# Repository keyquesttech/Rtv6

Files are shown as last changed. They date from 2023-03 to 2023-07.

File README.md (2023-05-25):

<p align="center" style="margin-bottom: 0px !important;">
 <a href="https://github.com/keyquesttech">
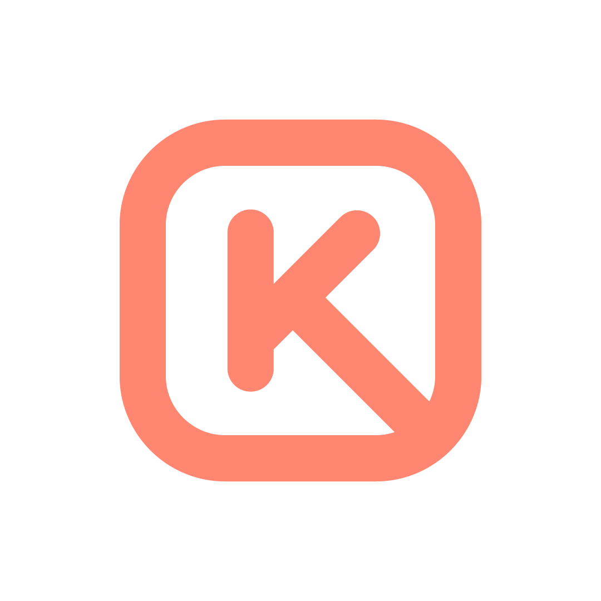
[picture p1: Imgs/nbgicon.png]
Keyquest logo
  
   <a href="https://www.behance.net/matiasms">
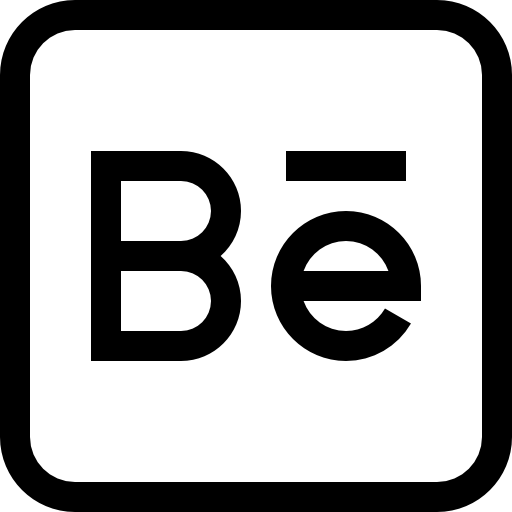
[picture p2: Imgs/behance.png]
    
</p>

<p align="center" style="margin-bottom: 0px !important;">
  <a href="https://igg.me/at/rtv6/x/33605500#/">
    
</p>
 
 <p align="center" style="margin-top: 200px !important;">
  <h2 align="center" style="margin-bottom: 100px;">For info and sales PM via discord at: TC#4730 or click the indiegogo image above</h2>
</p>
 
</div>
<p align="center" >RtV6</p>
<p align="center" >A rvo nozzle adapter to make any V6 nozzle a quick change nozzle</p>
<p align="center" >Rvo CHT? Rvo Diamond? Rvo Emerald?</p>
<p align="center" >All possible now.</p>
</div>

<div align="center" >
  
  
  


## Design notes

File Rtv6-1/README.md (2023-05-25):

<p align="center" style="margin-top: 100px !important;">
  <h2 align="center" style="margin-bottom: 0px;">RtV6 V1:</h2>
</p>

</div>

 - Brass Body.
 - Titanium alloy inner tube.
 - Adds 6mm from heater base to tip of nozzle.

<p align="center" style="margin-bottom: 0px !important;">
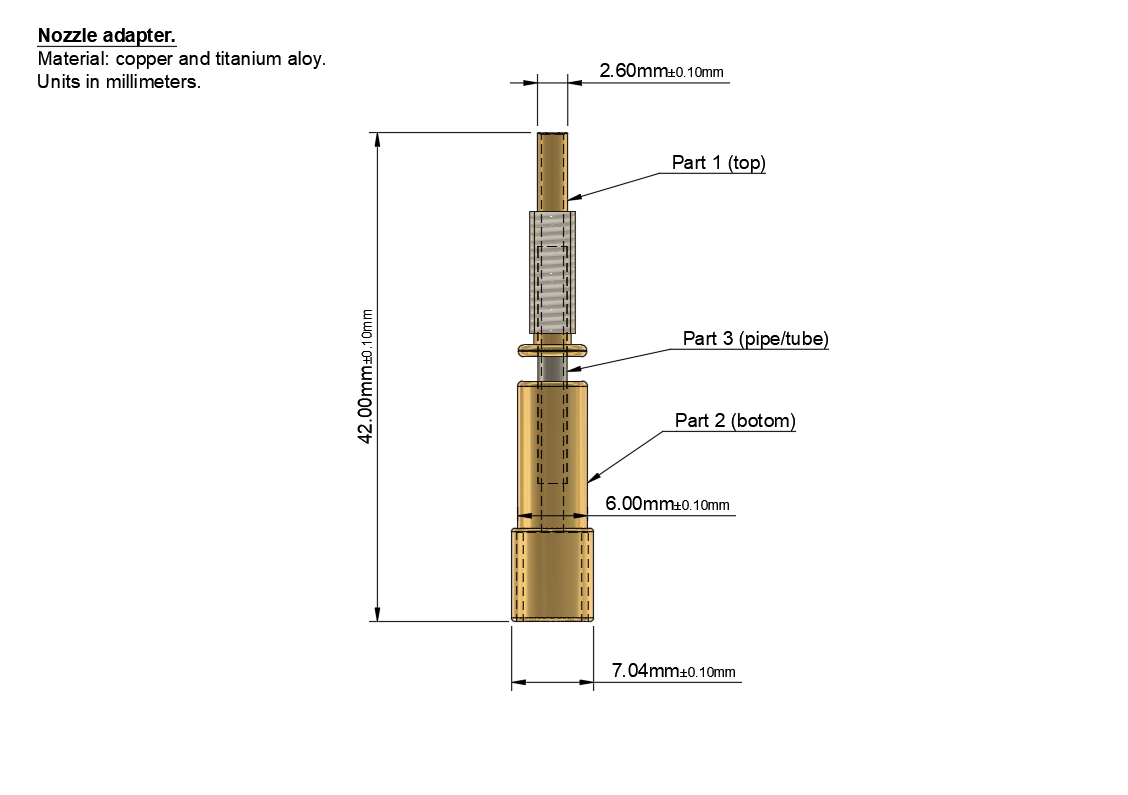
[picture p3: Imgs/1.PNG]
Keyquest logo
  
</p>

<p align="center" style="margin-top: 100px !important;">
  <h2 align="center" style="margin-bottom: 0px;">Tips and tricks:</h2>
</p>

**Nozzle soak:**
In general it's always a good idea to wait a bit to start printing to let the nozzle zoak and stabilize at the desired temperature, however for for the RtV6 nozzle adapter it's even more important.

As a starting point 1 minute is a good value. To do it add the following g-code to your print start right at the end of the code block:

    G4 S60

An improperly soaked/heated nozzle may result in poor print quality, bad bed adhesion, reduced flow or in the worst case 
a broken adapter, where the top and bottom pieces get separated due to the pressure inside the titanium tube pushing both ends apart.

**Print hotter:**
Due to the extra size of the adapter and the increase in mass you may need to print hotter. A good starting point is 10c hotter.

Start with +10c and do a temperature calibration print. You may automate this with a macro:

    [gcode_macro _PRINT_START]
	gcode:
    {% set hotendtemp = params.HOTEND|string %} #Extruder temp parameter
    M109 S{hotendtemp+10} #Set & wait for hotend temp

 Or do it manually
 
**Adjust Z offset:**
Since the adapter is 6mm taller than the standard rvo nozzle you will need to re-set you home offset, to do this there's many ways and some depend on your printer/setup. I'm sure you can figure this point out.

**Cooling solution:**
As mentioned above the nozzle is 6mm taller, so the standard Rvo cooling solution won't work. You will need to create your own, add stronger fans to your toolhead or add external cooling, just make sure it points to the part, otherwise you will reduce the performance of the adapter.

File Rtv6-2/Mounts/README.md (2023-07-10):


<table>
    <thead>
        <tr>
            <th align="left">Mount</th>
            <th align="center">Designer</th>
             <th align="center">Notes</th>
        </tr>
    </thead>
    <tbody>
        <tr>
            <td align="center">Mini_afterburner_0.2.stl</td>
            <td align="center">Matias M</td>
			<td align="center">Voron 0.2</td>
        </tr>
    </tbody>
        <tbody>
        <tr>
            <td align="center">Mini_afterburner_SLS.stl</td>
            <td align="center">Matias M</td>
                                    <td align="center">For SLS printing</td>
        </tr>
            <tbody>
                <tr>
            <td align="center">prusa-mk3s-fan_shroud.step</td>
            <td align="center">Olof Ogland</td>
                                                <td align="center">For Prusa</td>
        </tr>
    </tbody>
    </thead>
</table>

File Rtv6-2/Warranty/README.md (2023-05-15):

<p align="center" style="margin-bottom: 0px !important;">
 <a href="https://github.com/keyquesttech">
  Keyquest logo
   <a href="https://www.behance.net/matiasms">
    
</p>

 <p align="center" style="margin-top: 200px !important;">
  <h2 align="center" style="margin-bottom: 100px;">Warranty and product information:</h2>
</p>

</div>
<p align="center" >This product is provided as is, with no warranty KeyQuest shall not be liable for any defects that are caused by neglect, misuse or mistreatment by the customer, including improper installation or testing, or for any products that have been altered or modified in any way by a customer.</p>

<p align="center" >Cold extrusion may cause separation of one or many sections of the adapter.</p>

<p align="center" >With hardened steel nozzles you may need to print hotter.</p>
</div>

 <p align="center" style="margin-top: 200px !important;">
  <h2 align="center" style="margin-bottom: 100px;">First use instructions:</h2>
</p>

</div>
<p align="center" >Hot tighten the nozzle: Method 1</p>

 1. Insert the adapter in to the Revo hotend.
 2. Heat up as normal.
 3. Once hot tighten the V6 nozzle while holding the sock.

</div>

<p align="center" >Hot tighten the nozzle: Method 2</p>

 1. Insert the adapter in to the Revo hotend.
 2. Heat up as normal.
 3. Once hot remove the adapter from the Revo hotend.
 4. Tigten the V6 nozzle on to the adapter.

</div>

 <p align="center" style="margin-top: 200px !important;">
  <h2 align="center" style="margin-bottom: 100px;">Print instructions</h2>
</p>

<p align="center" >Calibration:</p>

 Start by heating up 5 to 10c more than normal your hotend, for example:

    No adapter PLA print temp: 220c.
    With adapter PLA print temo: 225 - 230c.

Extrude some plastic and asess the situation. *start hotter and go down from there.

In adition to printing hotter adding a delay to your print start may be usefull, 30 to 60 seconds works great. Alternatively you can heat the hotend first and then the bed.

</div>

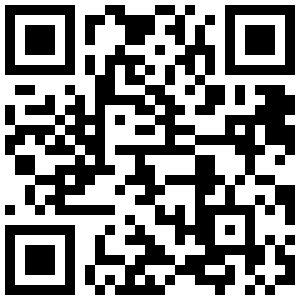
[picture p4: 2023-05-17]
Rtv6-2/Package/Card_assets/Discord.png

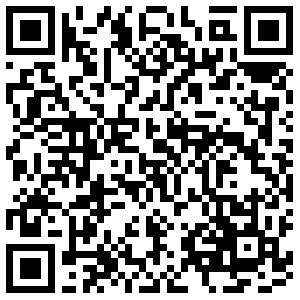
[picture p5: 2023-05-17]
Rtv6-2/Package/Card_assets/Warranty.png

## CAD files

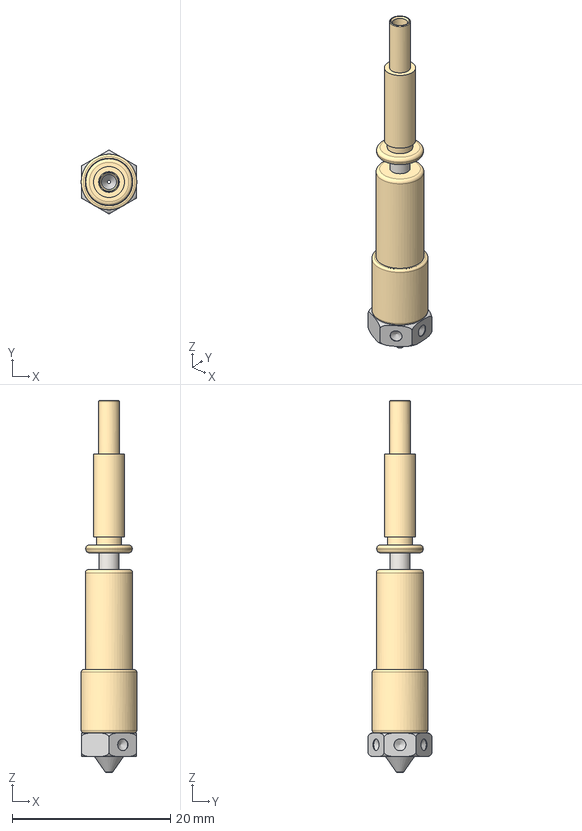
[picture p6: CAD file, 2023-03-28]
Rtv6-1/RtV6-1.step
7.04 x 8.08 x 47.0 mm
Bottom
Top
Tube
3695N121_3D Printer Nozzle (1)

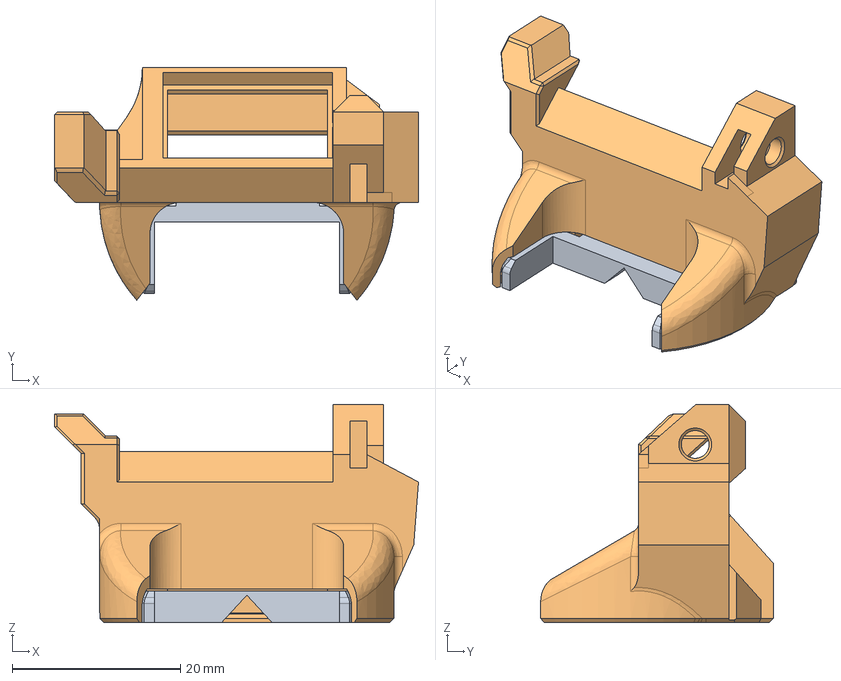
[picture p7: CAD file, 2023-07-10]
Rtv6-2/Mounts/prusa-mk3s-fan_shroud.step
43.2 x 27.6 x 25.9 mm

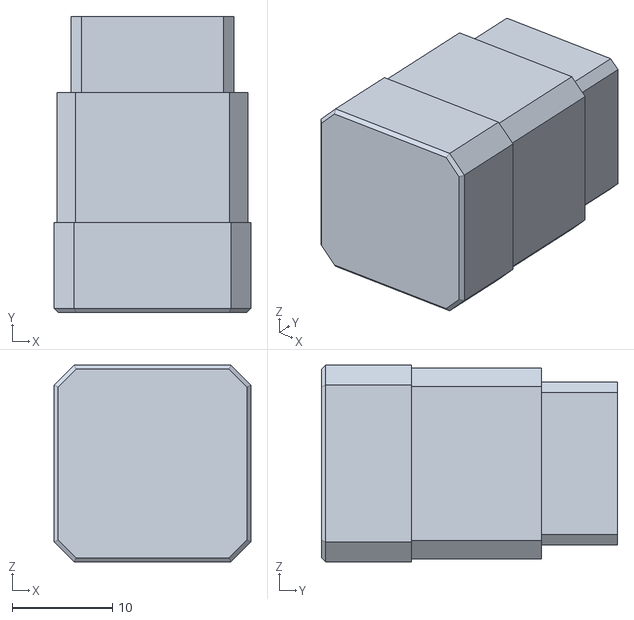
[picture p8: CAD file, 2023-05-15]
Rtv6-2/Package/Btm_Adapter.stl
19.6 x 29.5 x 19.6

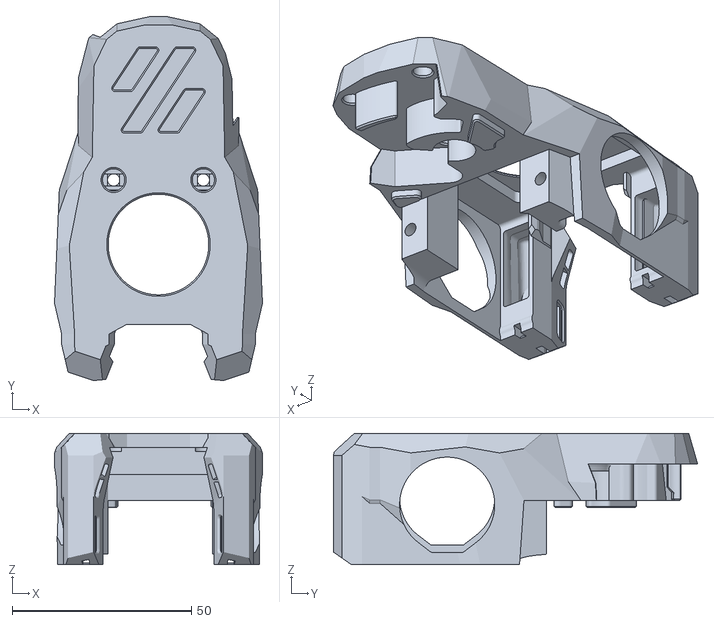
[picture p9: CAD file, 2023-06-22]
Rtv6-2/Mounts/Mini_afterburner_0.2.stl
57.9 x 101.5 x 36.5

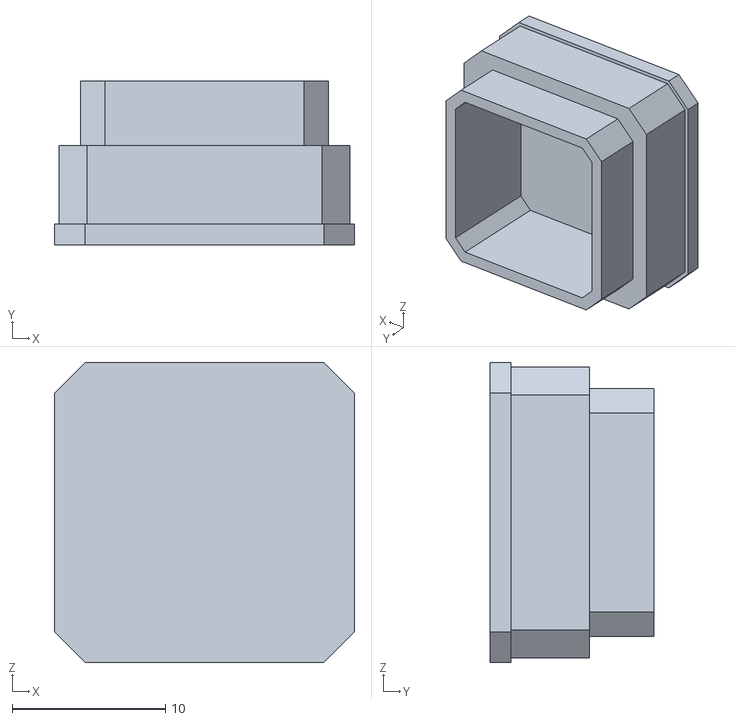
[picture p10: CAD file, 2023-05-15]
Rtv6-2/Package/Sock_btm.stl
19.6 x 10.7 x 19.6

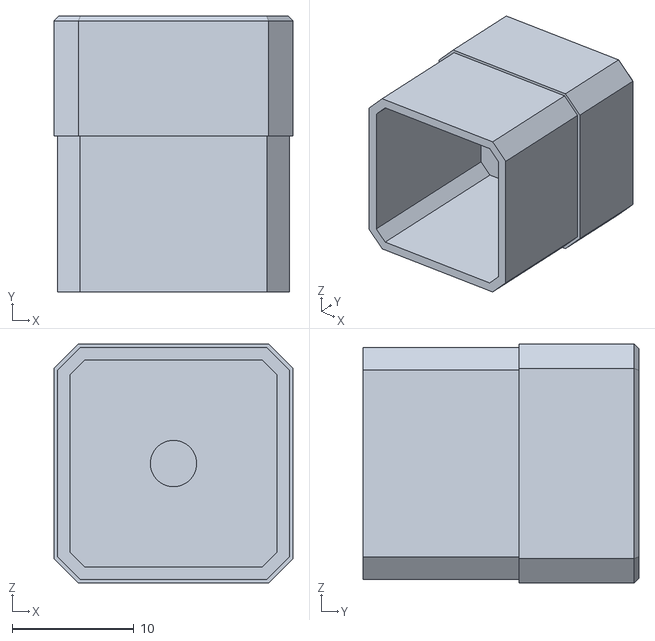
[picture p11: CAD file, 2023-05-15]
Rtv6-2/Package/Top_Adapter.stl
19.6 x 22.6 x 19.6

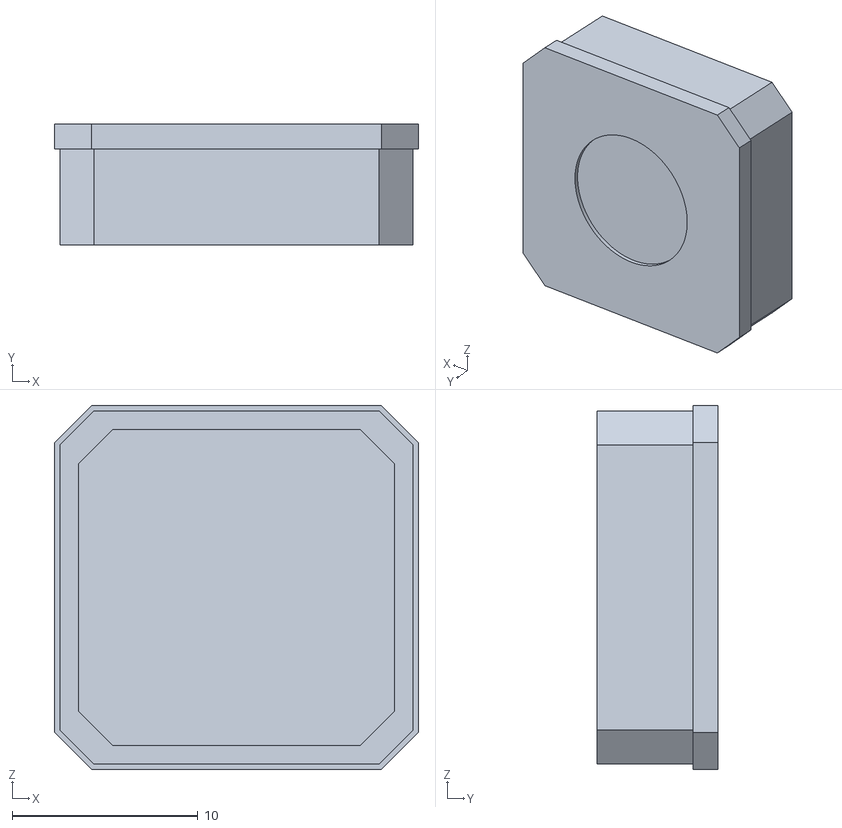
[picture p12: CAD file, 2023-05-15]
Rtv6-2/Package/Sock_top.stl
19.6 x 6.50 x 19.6

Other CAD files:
Rtv6-1/RtV6-1.f3d
Rtv6-2/CAD/RtV6-2.f3d

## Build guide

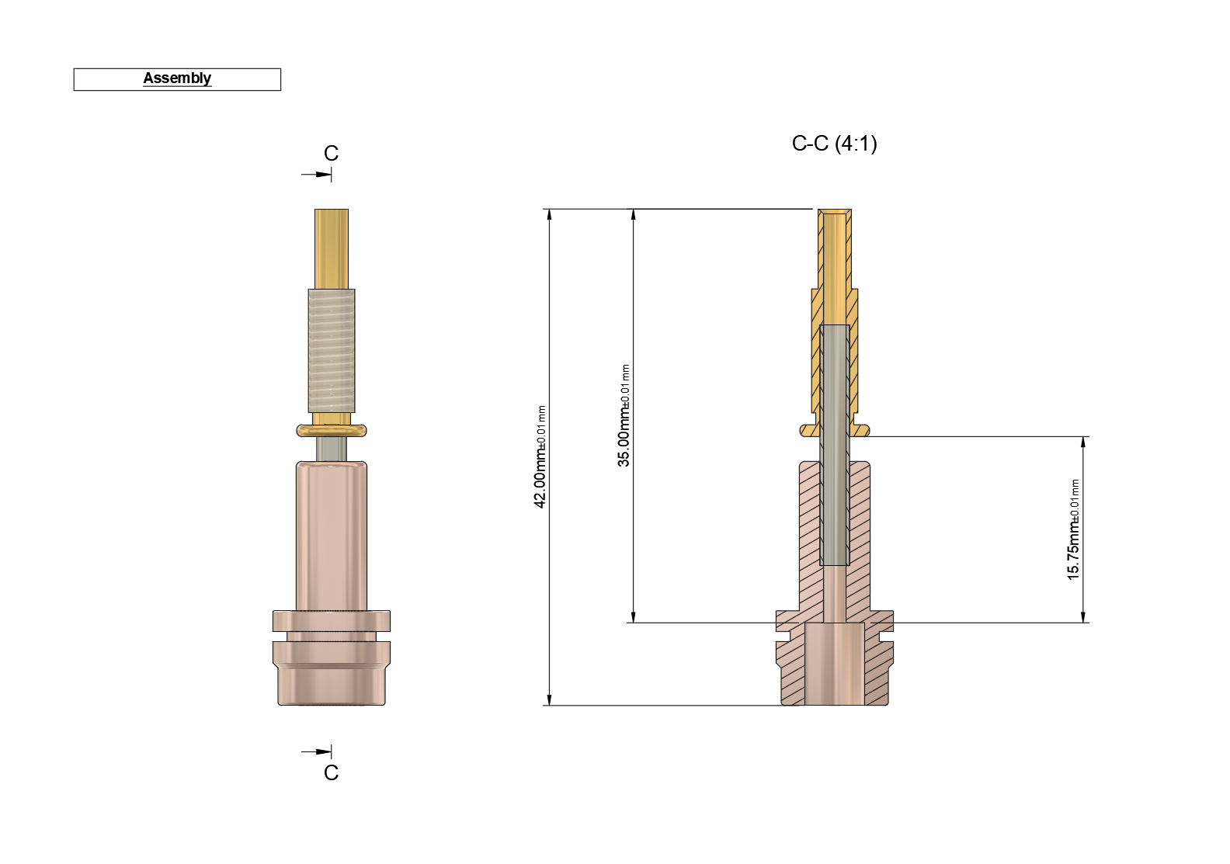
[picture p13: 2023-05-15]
Imgs/RtV6-2-assembly.PNG

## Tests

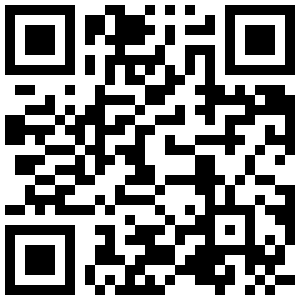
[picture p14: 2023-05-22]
Rtv6-2/Package/Card_assets/Verification.png

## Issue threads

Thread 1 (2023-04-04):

Z offset is only 6mm taller than standard revo

ecgraffcam, 2023-04-04:
You describe the adapter as being 13mm taller than a standard Revo nozzle. It is only 6mm taller.
Starting after the heat block the adapter + a v6 nozzle are 13mm tall and a standard revo nozzle is 7mm tall.

keyquesttech, 2023-04-04:
You're absolutely right. I was counting from the bottom of the stock mini afterburner.

Closed 2023-04-04.

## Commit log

2023-04-05 name changes
    [RtV6-1.f3d, RtV6-1.step, Sockv1.step]
2023-06-22 Added mount
    Added RtV6 V2 mount for voron 0.2 or similar hotend printers
    [Mini_afterburner_0.2.stl]
2023-07-10 prusa mnt
    [prusa-mk3s-fan_shroud.step]
